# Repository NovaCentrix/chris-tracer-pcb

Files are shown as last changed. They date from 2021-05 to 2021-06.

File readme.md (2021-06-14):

# The TraceR 

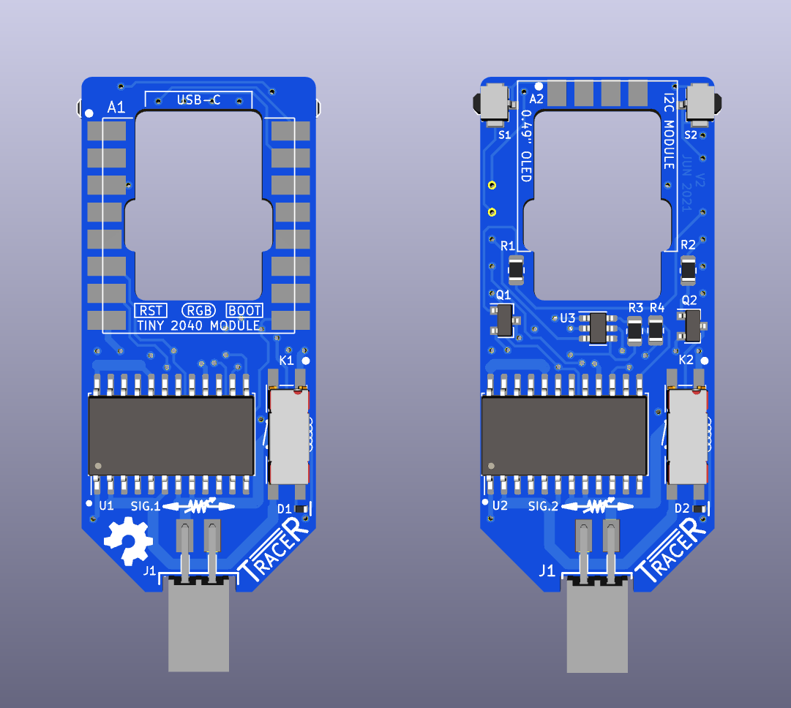
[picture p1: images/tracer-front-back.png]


## A Module for Simulating Conductive Ink PCB Traces

## Revisions

### Version 2

* Digipot power supply from from 3.3 to 5, in order to reduce the wiper
  resistance further (see the datasheet). This means the addition of
  level translator for the MISO signal into the MCU. 

* The digipot SDO pin is open drain. Added pullup resistors on each one.

* Assembly of modules onto v1 board was difficult. And the whole assembly 
  needs to be thinner so two modules can be installed adjacent to each
  other (relates to the pin header spacing on the main board). Gave up
  on the idea of avoiding a board cutout. Re-routing of signals, and
  made the board just slightly larger (mostly taller) to allow for the
  required cutout.

* Changed PCB thickness from 1.6 to 1.0 mm.

* Found some tiny buttons (about the same size as those on the Tiny 2040
  module) and put them at the top corners. This will allow the user to
  change resistance values without using the serial port.

### Version 1

First release. 

## Observations

Before I forget, here are some thoughts to consider if there ever is
going to be a version 3.

* Make D1/D2 larger, since that package is nearly impossible to hand
  solder. Or...

* Make the transistor and resistor packages smaller and reflow rather
  than hand solder. Also, Digipots are available in a smaller package:
    * TSSOP-24 package 7.8 x 4.4 mm 
    * SOIC-24W 15.4 x 7.5 mm (currently used)

* Look carefully at the Adafruit Qt Py RP2040 module. It looks smaller,
  has a smaller and well-defined required cutout and mechanical
  drawings. Fewer pins.

* Save even more space my tossing the module concept and building the
  RP2040 board and the OLED module directly on the TraceR's PCB.

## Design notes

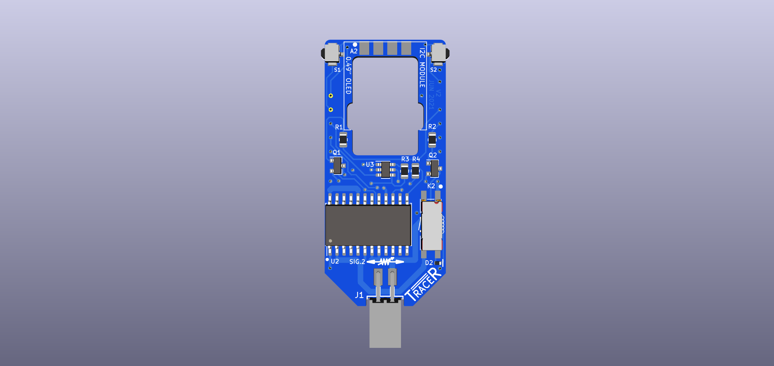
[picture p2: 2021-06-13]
images/tracer-back-view.png

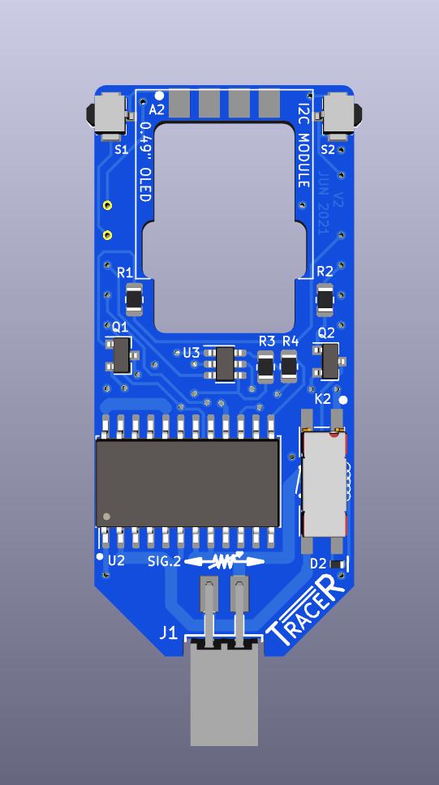
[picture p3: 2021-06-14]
images/b.png

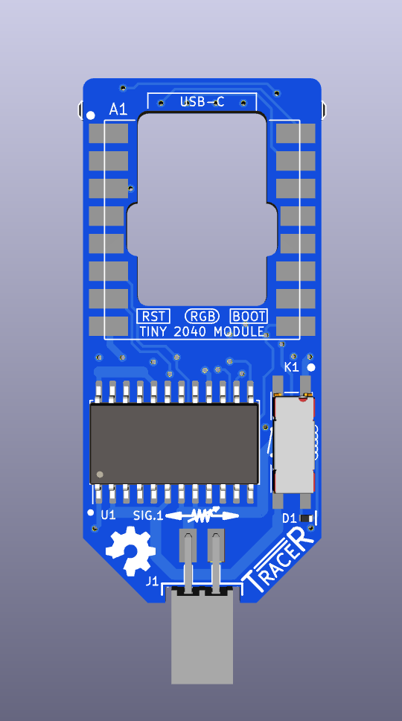
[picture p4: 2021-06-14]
images/f.png

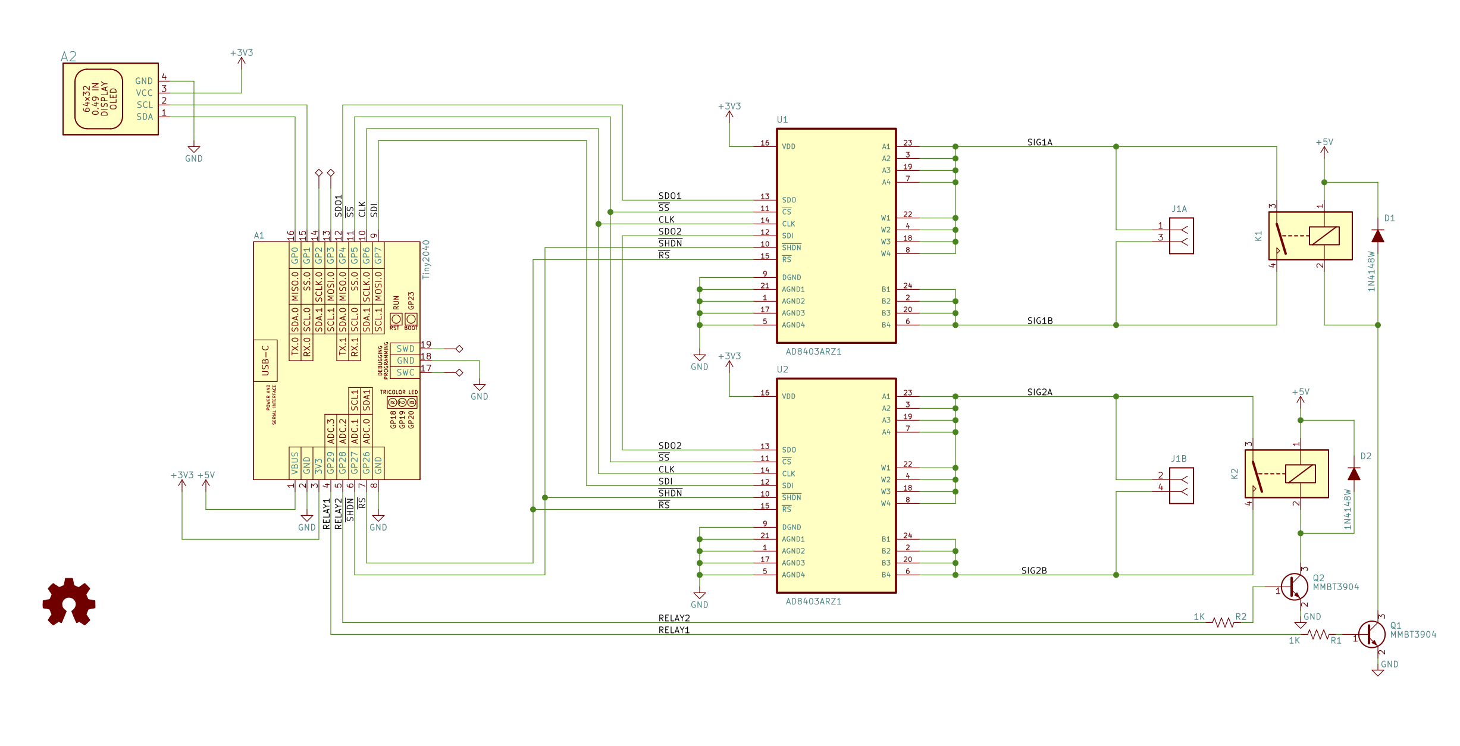
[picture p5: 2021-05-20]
tracer-sch.png

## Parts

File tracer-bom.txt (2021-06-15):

Reference	 Quantity	 Value	 Footprint	 Datasheet	 MANUFACTURER
A1 	1	"Tiny2040"	".tracer:MODULE_TINY_2040_DEV2"	""
A2 	1	"ASSY_OLED_490MILS_62x32_I2C"	".tracer:MODULE_OLED_490_SMALL_PADS"	""
U1 U2 	2	"AD8403ARZ1"	".tracer:SOIC-24W_7.5x15.4mm_P1.27mm"	""
U3 	1	"TXS0101"	".tracer:SOT-23-6"	""
Q1 Q2 	2	"MMBT3904"	".tracer:SOT-23"	"https://www.onsemi.com/pub/Collateral/2N3903-D.PDF"
D1 D2 	2	"1N4148W"	".tracer:DFN1006-2"	""
R1 R2 R3 R4 	4	"1K"	".tracer:R_0805_2012Metric"	""
K1 K2 	2	"Coto-9913-05-20"	".tracer:REED_RELAY_COTO_9913"	""
S1 S2 	2	"B3U-3100P-B"	".tracer:SW_B3U-3100P-B"	""	"Omron"
J1 	1	"IO_JACK_F04_SPLIT"	".tracer:SAMTEC-SSQ-102-02-SIDEWAYS"	""

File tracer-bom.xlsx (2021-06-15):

FN | QTY | REFDES | COMM | Mfr | PartNo | Item | Digikey P/N w/ Link
1 | 2 | U1 U2 | IC | Analog Devices | AD8403ARZ1 | IC, Analog, Digital Potentiometer | AD8403ARZ1-ND (https://www.digikey.com/en/products/detail/analog-devices-inc/AD8403ARZ1/997973)
2 | 1 | U3 | IC | Texas Instruments | TXS0101DBVR | IC, Level Translator, Single Gate | https://www.digikey.kr/product-detail/en/texas-instruments/TXS0101DBVR/2156-TXS0101DBVR-ND/13474289
3 | 2 | Q1 Q2 | SEMI | Diodes Inc | MMBT3904-7-F | Transistor, NPN, General Purpose 2N3904 SMD | MMBT3904-FDICT-ND (https://www.digikey.com/product-detail/en/diodes-incorporated/MMBT3904-7-F/MMBT3904-FDICT-ND/815727)
4 | 2 | D1 D2 | SEMI | MCC | 1N4148WL2 | Diode, General Purpose Signal 1N4148 SMD | 1N4148WL2-TPMSCT-ND (https://www.digikey.com/product-detail/en/micro-commercial-co/1N4148WL2-TP/1N4148WL2-TPMSCT-ND/6193205)
5 | 4 | R1 - R4 | RES | Yageo | RC0805JR-071KL |  | https://www.digikey.com/en/products/detail/yageo/RC0805JR-071KL/728218
6 | 2 | K1 K2 | REL | Coto Technology | 9913-05-20TR | Relay, Reed, 1 Form A, 5VDC Coil, SMD | 306-1415-1-ND (https://www.digikey.com/product-detail/en/coto-technology/9913-05-20TR/306-1415-1-ND/7398787)
7 | 2 | S1 S2 | SWI | Omron | B3U-3100P-B |  | https://www.digikey.com/en/products/detail/omron-electronics-inc-emc-div/B3U-3100P-B/1811780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
8 | 1 | J1 | CON | Samtec | SSQ-102-02-G-D | Connector, Pin Socket, 0.1 in pitch, 4 posn 2x2, Thruhole, Gold plating | SAM1185-02-ND (https://www.digikey.com/product-detail/en/samtec-inc/SSQ-102-02-G-D/SAM1185-02-ND/1110865)
2021-06-15 | Yellow items are new
2021-06-15 | Greeh highlight item is to buy

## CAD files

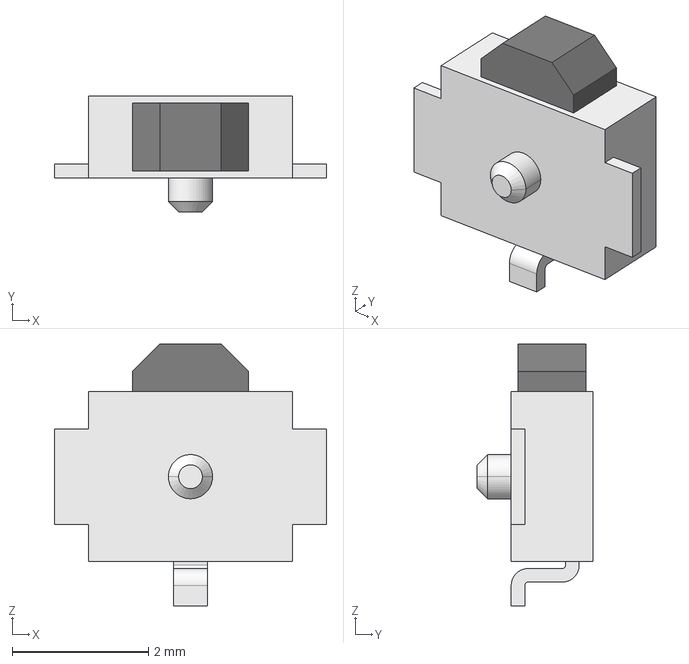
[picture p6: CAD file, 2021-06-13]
tracer.packages3d/b3u-3100p-b.stp
4.00 x 1.70 x 3.85 mm

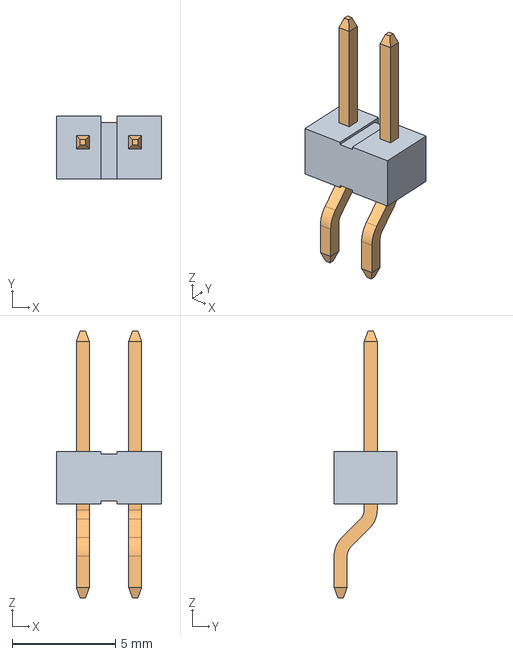
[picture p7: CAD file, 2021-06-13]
tracer.packages3d/TSM-102-01-L-SH.step
5.08 x 3.05 x 13.0 mm
_TSM-102-01-SH_body
_T-1S6-08(-01-2-SH)

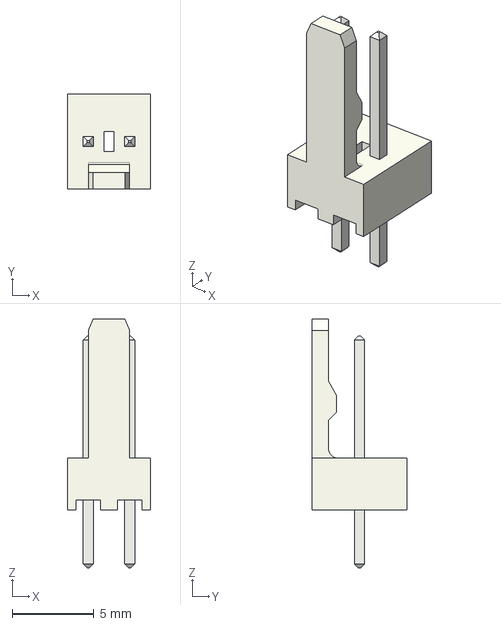
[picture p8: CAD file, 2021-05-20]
tracer.packages3d/Molex_KK-254_AE-6410-02A_1x02_P2.54mm_Vertical.step
5.08 x 5.80 x 15.3 mm

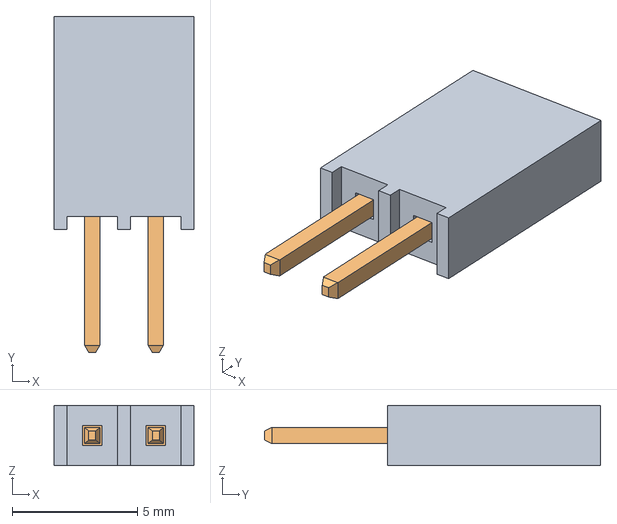
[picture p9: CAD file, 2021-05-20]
tracer.packages3d/SSQ-102-02-G-S.step
5.59 x 13.4 x 2.41 mm
_T1SSQ-102-02-G-S
_P2SSQ-102-02-G-S

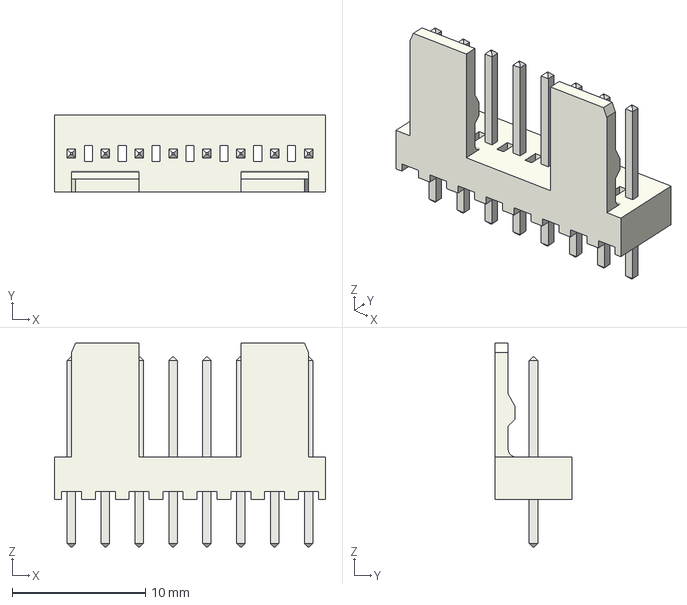
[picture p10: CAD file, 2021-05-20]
tracer.packages3d/Molex_KK-254_AE-6410-08A_1x08_P2.54mm_Vertical.step
20.3 x 5.80 x 15.3 mm

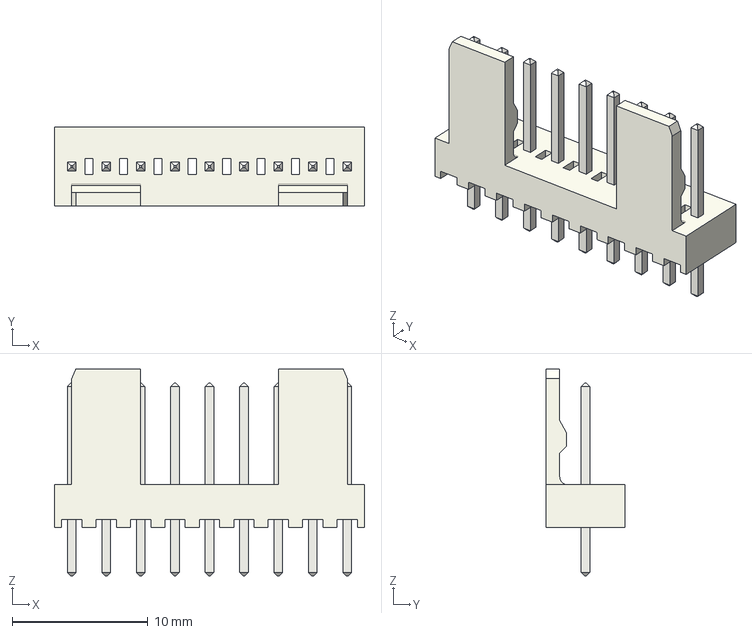
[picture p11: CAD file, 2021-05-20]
tracer.packages3d/Molex_KK-254_AE-6410-09A_1x09_P2.54mm_Vertical.step
22.9 x 5.80 x 15.3 mm

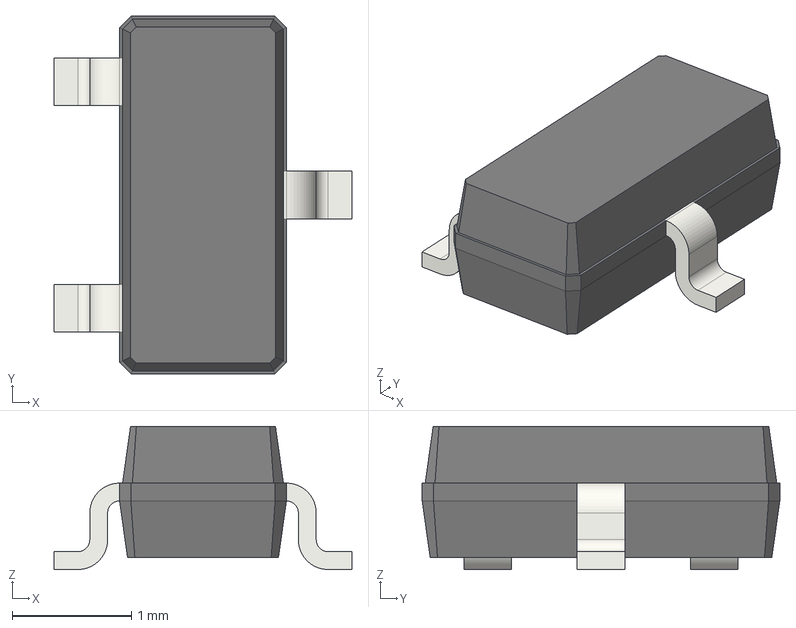
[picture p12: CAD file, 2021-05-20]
tracer.packages3d/SOT-23.step
2.50 x 3.00 x 1.20 mm

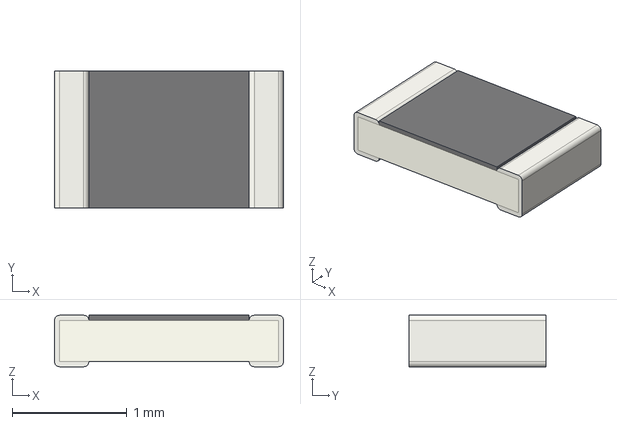
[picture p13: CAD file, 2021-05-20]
tracer.packages3d/R_0805_2012Metric.step
2.00 x 1.20 x 0.45 mm

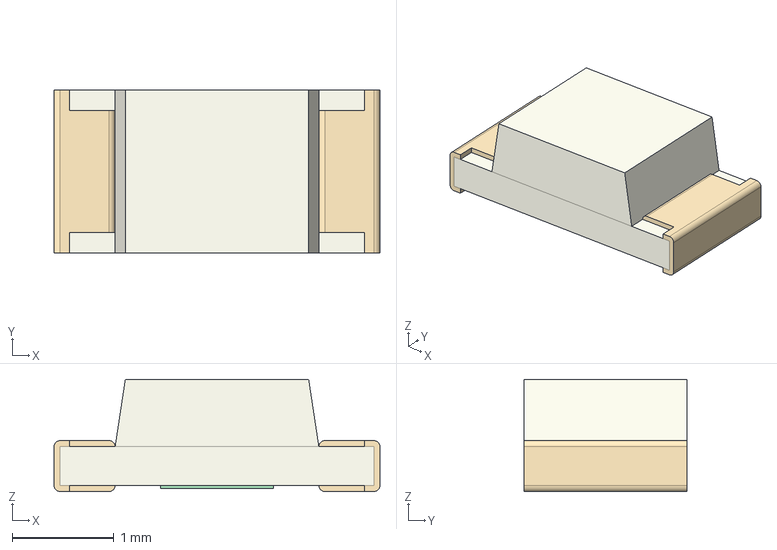
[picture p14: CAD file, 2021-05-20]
tracer.packages3d/LED_1206_3216Metric.step
3.20 x 1.60 x 1.10 mm

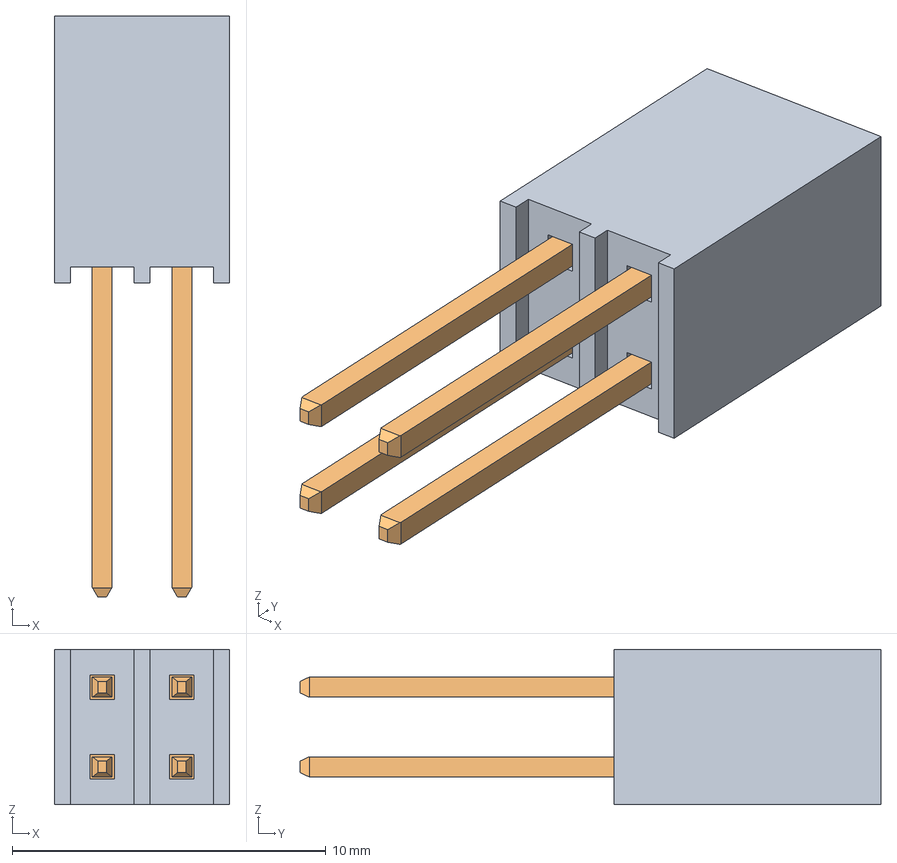
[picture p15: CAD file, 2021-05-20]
tracer.packages3d/SSQ-102-03-G-D.step
5.59 x 18.5 x 4.95 mm
_T1SSQ-102-03-G-D
_P2SSQ-102-03-G-D

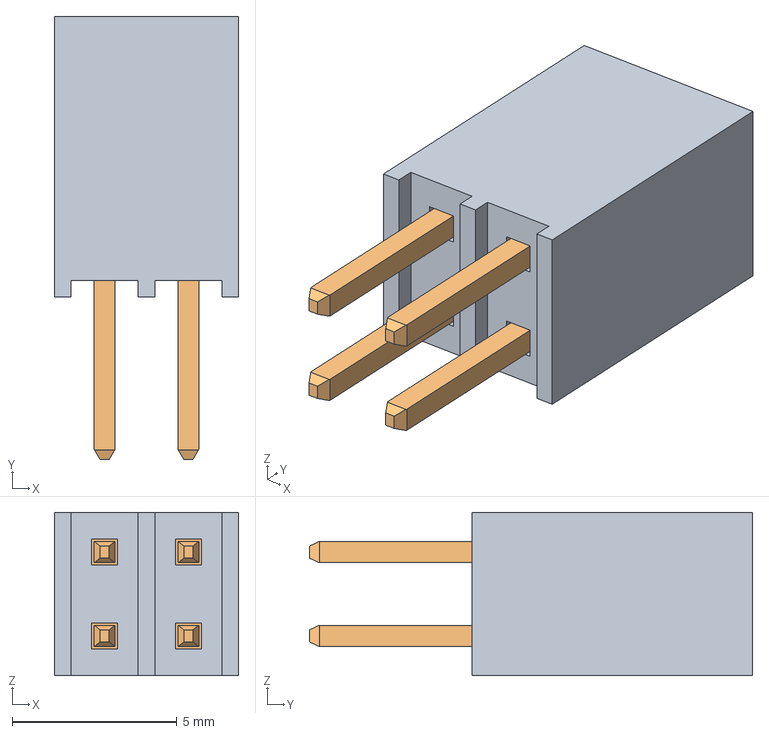
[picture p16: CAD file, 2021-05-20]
tracer.packages3d/SSQ-102-02-G-D.step
5.59 x 13.4 x 4.95 mm
_T1SSQ-102-02-G-D
_P2SSQ-102-02-G-D

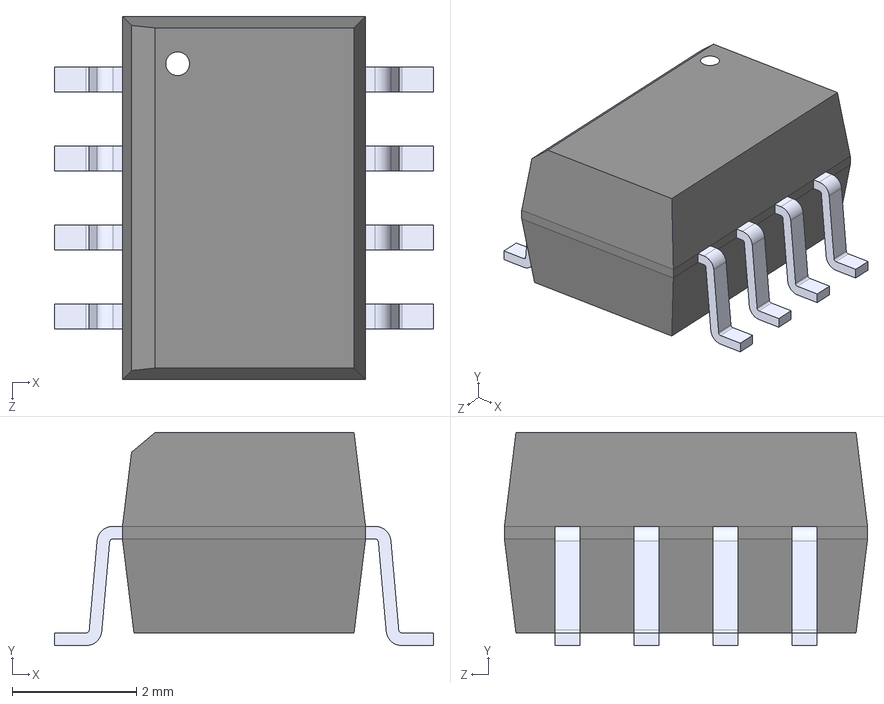
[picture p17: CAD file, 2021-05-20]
tracer.packages3d/ild213t.step
6.10 x 3.43 x 5.84 mm

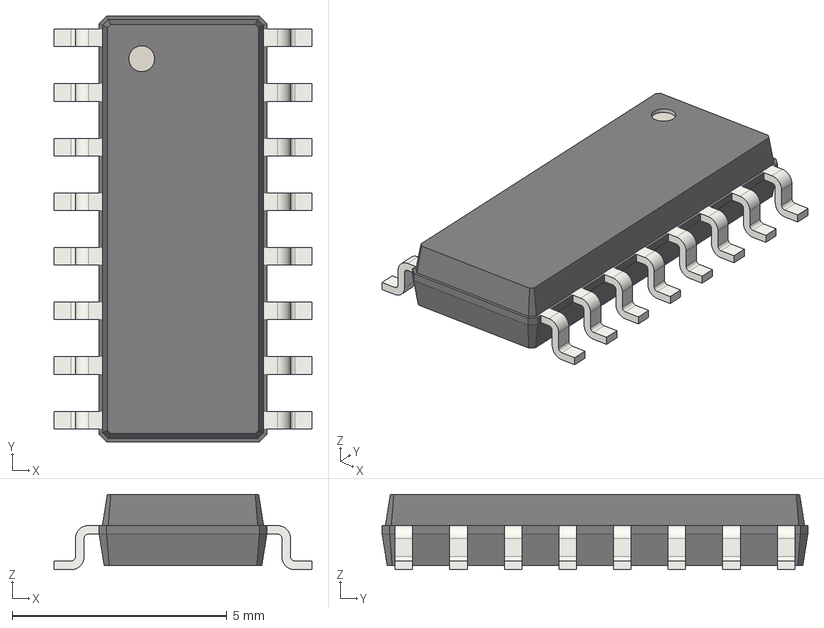
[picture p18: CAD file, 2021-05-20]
tracer.packages3d/SOIC-16_3.9x9.9mm_P1.27mm.step
6.00 x 9.90 x 1.75 mm

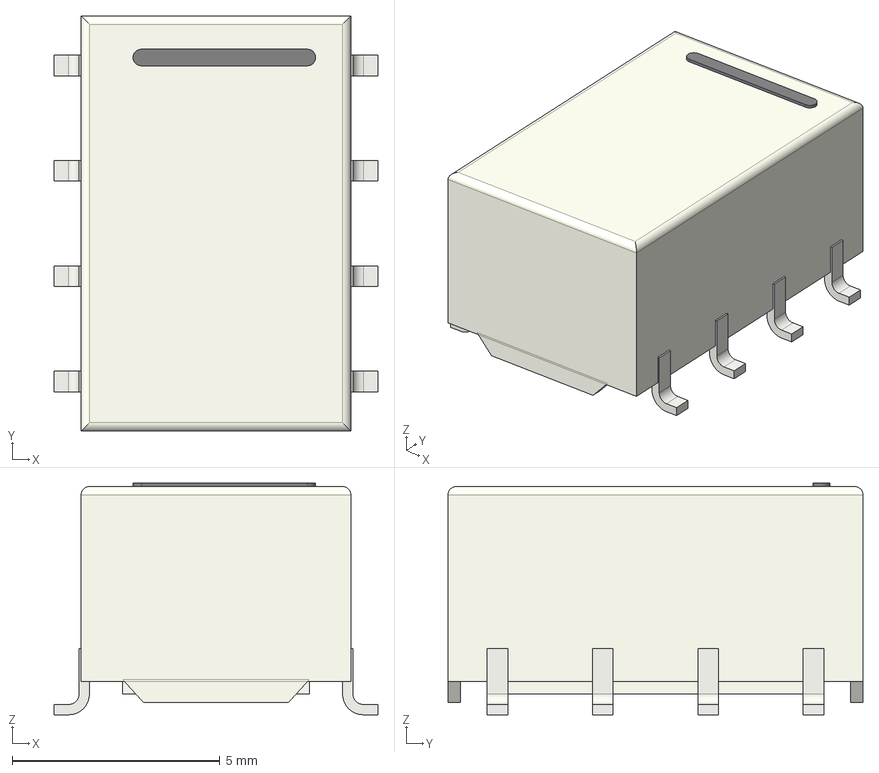
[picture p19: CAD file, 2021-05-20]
tracer.packages3d/Relay_DPDT_Omron_G6K-2F.step
7.80 x 10.0 x 5.58 mm

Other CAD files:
tracer.packages3d/plcc-2-package-3d.stp
tracer.packages3d/9913_stp.stp
tracer.packages3d/LED_1210_3225Metric.step
tracer.packages3d/Molex_KK-254_AE-6410-04A_1x04_P2.54mm_Vertical.step
tracer.packages3d/DFN1006-2.stp

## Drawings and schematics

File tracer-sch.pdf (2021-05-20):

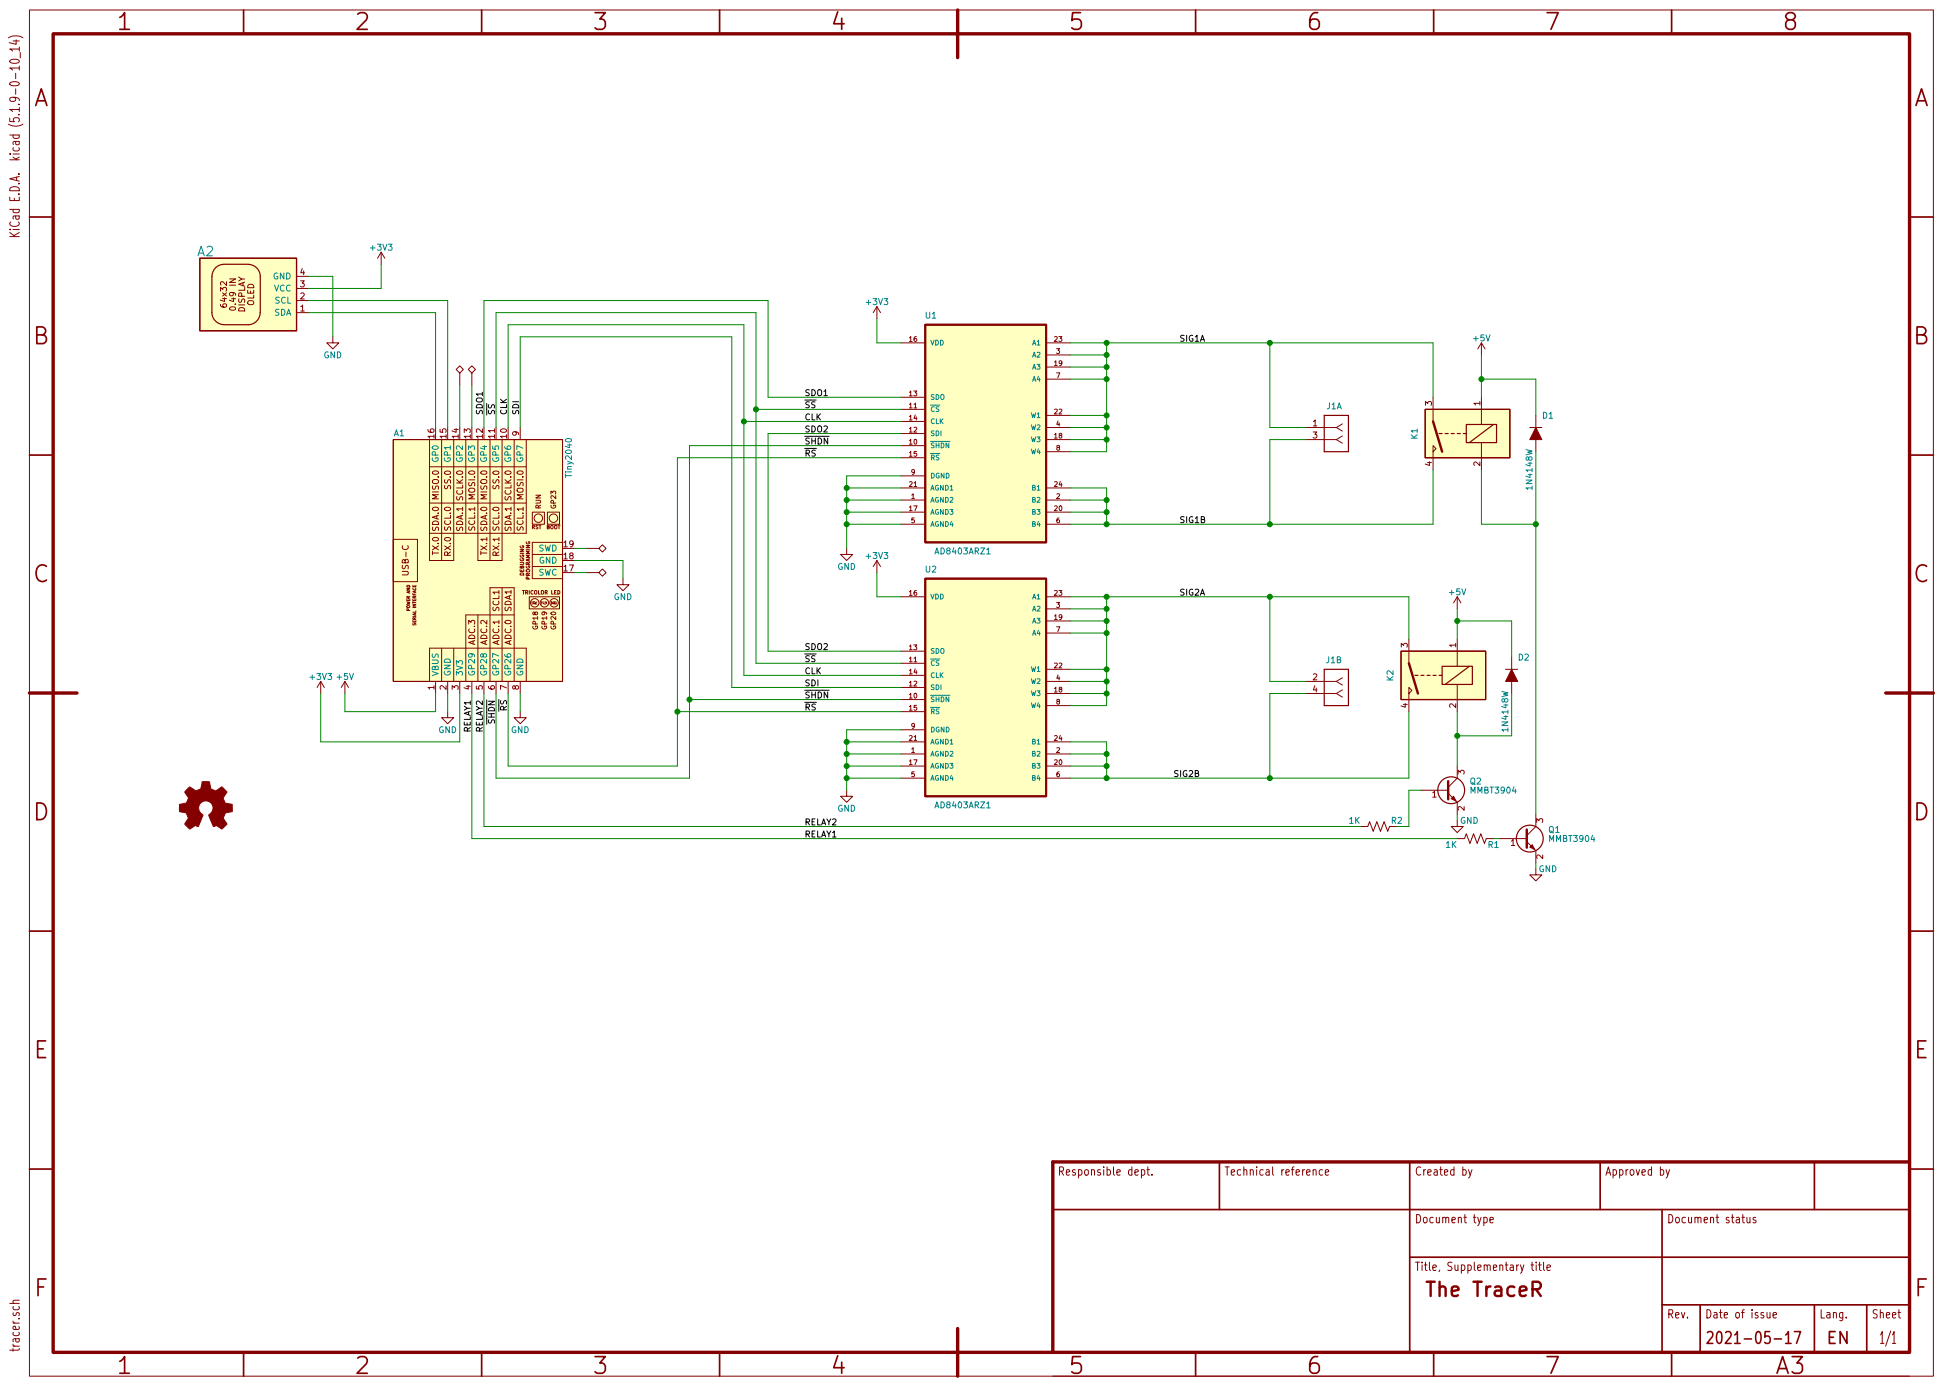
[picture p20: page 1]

The TraceR KiCad E.D.A. kicad (5.1.9-0-10_14)

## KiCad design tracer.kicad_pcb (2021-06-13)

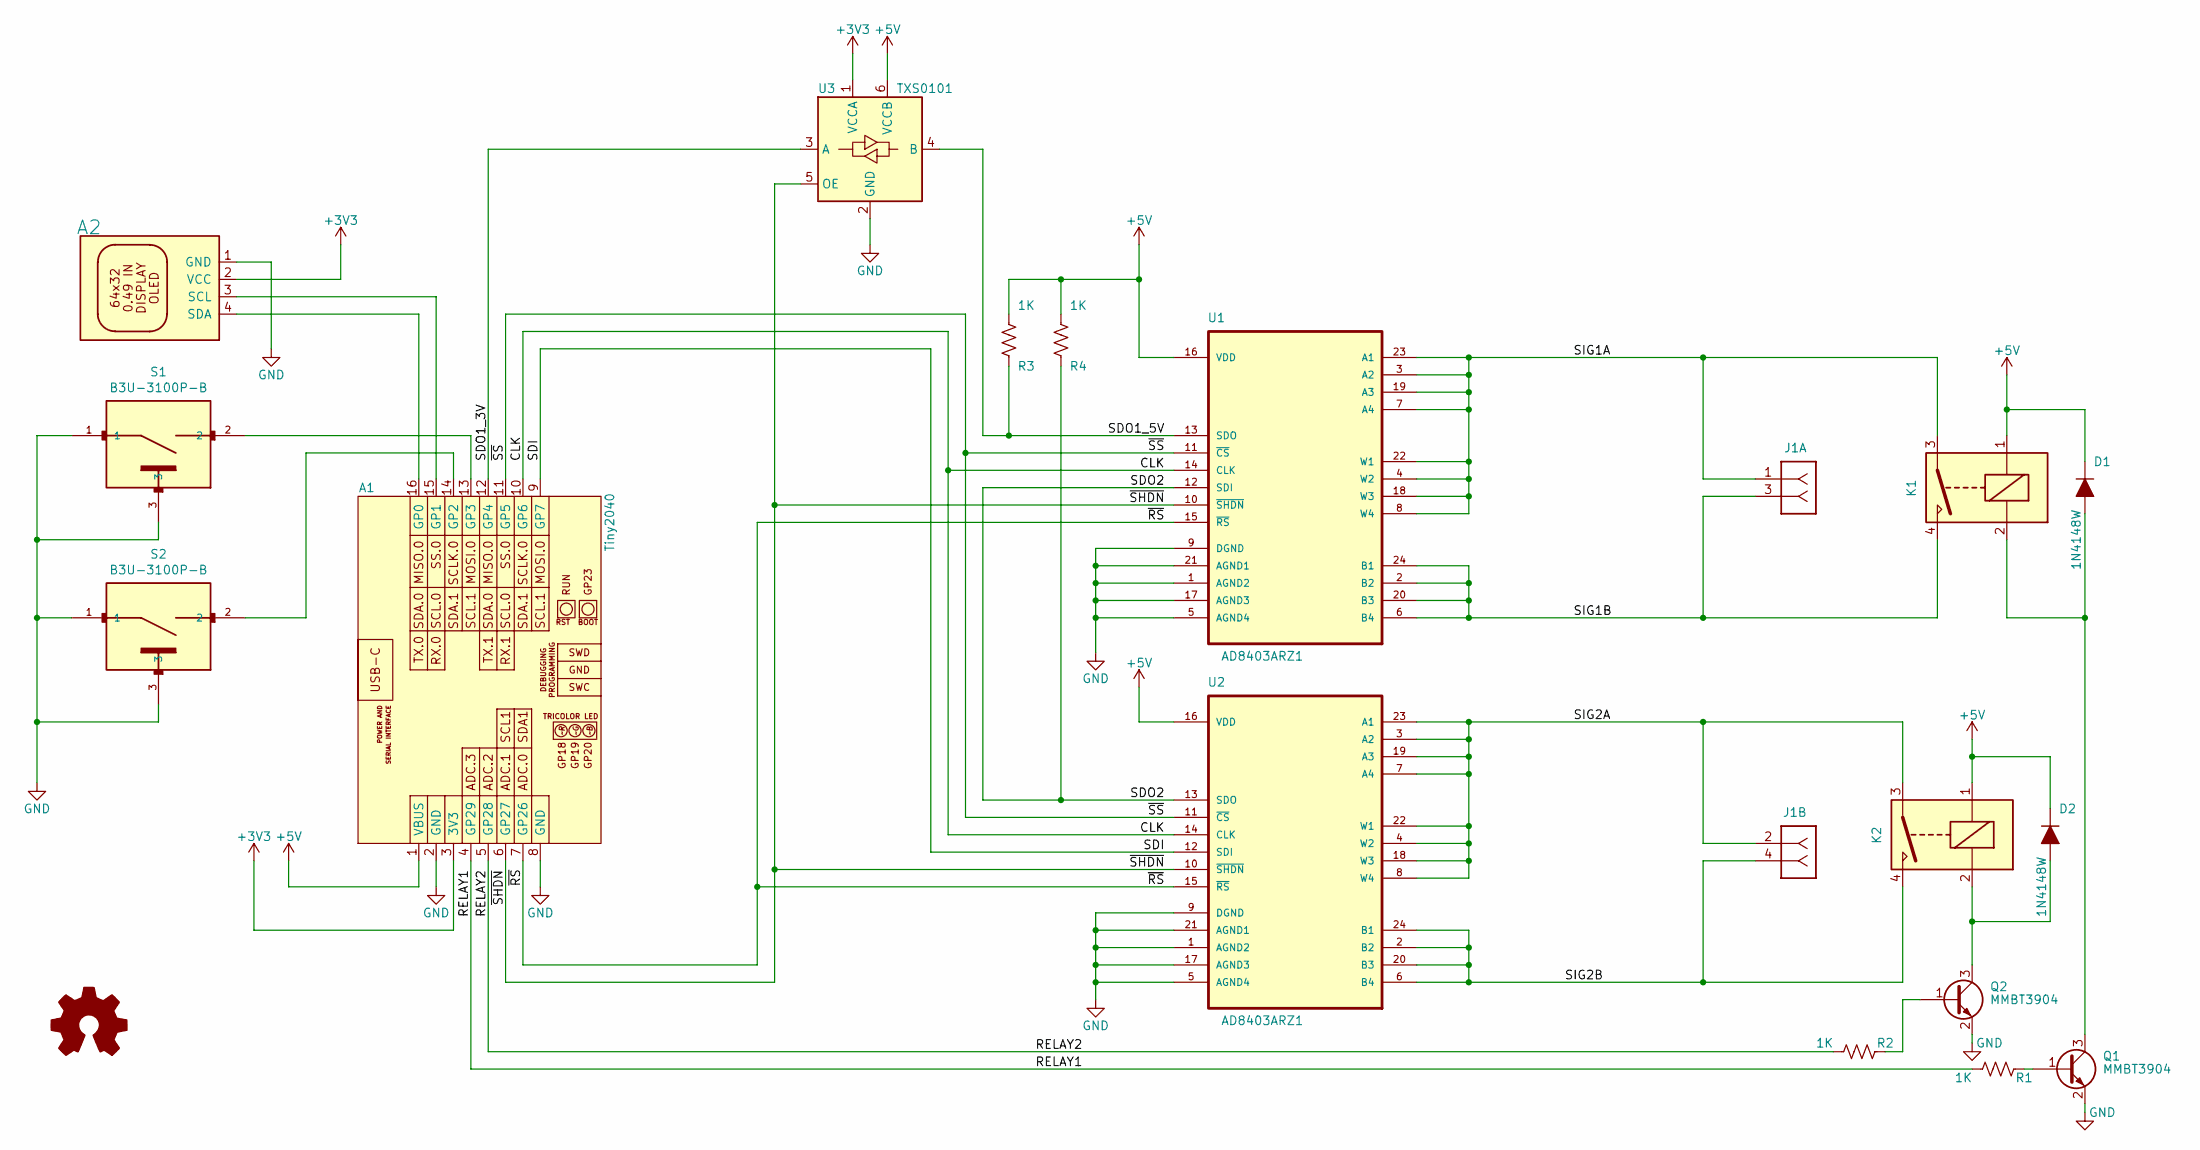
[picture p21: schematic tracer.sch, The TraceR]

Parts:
A1: Tiny2040; MODULE_TINY_2040_DEV2
A2: ASSY_OLED_490MILS_62x32_I2C; MODULE_OLED_490_SMALL_PADS
D1, D2: 1N4148W; DFN1006-2
J1: IO_JACK_F04_SPLIT; SAMTEC-SSQ-102-02-SIDEWAYS
K1, K2: Coto-9913-05-20; REED_RELAY_COTO_9913
LOGO1: Logo_Open_Hardware_Small; OSHW-Logo2_7.3x6mm_SilkScreen
Q1, Q2: MMBT3904; SOT-23
R1, R2, R3, R4: 1K; R_0805_2012Metric
S1, S2: B3U-3100P-B; SW_B3U-3100P-B
U1, U2: AD8403ARZ1; SOIC-24W_7.5x15.4mm_P1.27mm
U3: TXS0101; SOT-23-6

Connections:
+3V3: A1.3 (3V3), A2.2 (VCC), U3.1 (VCCA)
+5V: A1.1 (VBUS), D1.1 (K), D2.1 (K), K1.1, K2.1, R3.2, R4.2, U1.16 (VDD), U2.16 (VDD), U3.6 (VCCB)
/CLK: A1.10 (GP6), U1.14 (CLK), U2.14 (CLK)
/RELAY1: A1.4 (GP29), R1.2
/RELAY2: A1.5 (GP28), R2.2
/SDI: A1.9 (GP7), U2.12 (SDI)
/SDO1_3V: A1.12 (GP4), U3.3 (A)
/SDO1_5V: R3.1, U1.13 (SDO), U3.4 (B)
/SDO2: R4.1, U1.12 (SDI), U2.13 (SDO)
/SIG1A: J1.1, K1.3, U1.3 (A2), U1.4 (W2), U1.7 (A4), U1.8 (W4), U1.18 (W3), U1.19 (A3), U1.22 (W1), U1.23 (A1)
/SIG1B: J1.3, K1.4, U1.2 (B2), U1.6 (B4), U1.20 (B3), U1.24 (B1)
/SIG2A: J1.2, K2.3, U2.3 (A2), U2.4 (W2), U2.7 (A4), U2.8 (W4), U2.18 (W3), U2.19 (A3), U2.22 (W1), U2.23 (A1)
/SIG2B: J1.4, K2.4, U2.2 (B2), U2.6 (B4), U2.20 (B3), U2.24 (B1)
/~RS: A1.7 (GP26), U1.15 (~RS), U2.15 (~RS)
/~SHDN: A1.6 (GP27), U1.10 (~SHDN), U2.10 (~SHDN), U3.5 (OE)
/~SS: A1.11 (GP5), U1.11 (~CS), U2.11 (~CS)
GND: A1.2 (GND), A1.8 (GND), A2.1 (GND), Q1.2 (E), Q2.2 (E), S1.1, S1.3, S2.1, S2.3, U1.1 (AGND2), U1.5 (AGND4), U1.9 (DGND), U1.17 (AGND3), U1.21 (AGND1), U2.1 (AGND2), U2.5 (AGND4), U2.9 (DGND), U2.17 (AGND3), U2.21 (AGND1), U3.2 (GND)
unnamed 17: A1.13 (GP3), S1.2; also elsewhere on the board
unnamed 18: A1.14 (GP2), S2.2; also elsewhere on the board
unnamed: A1.15 (GP1), A2.3 (SCL)
unnamed: A1.16 (GP0), A2.4 (SDA)
unnamed: D1.2 (A), K1.2, Q1.3 (C)
unnamed: D2.2 (A), K2.2, Q2.3 (C)
unnamed: Q1.1 (B), R1.1
unnamed: Q2.1 (B), R2.1

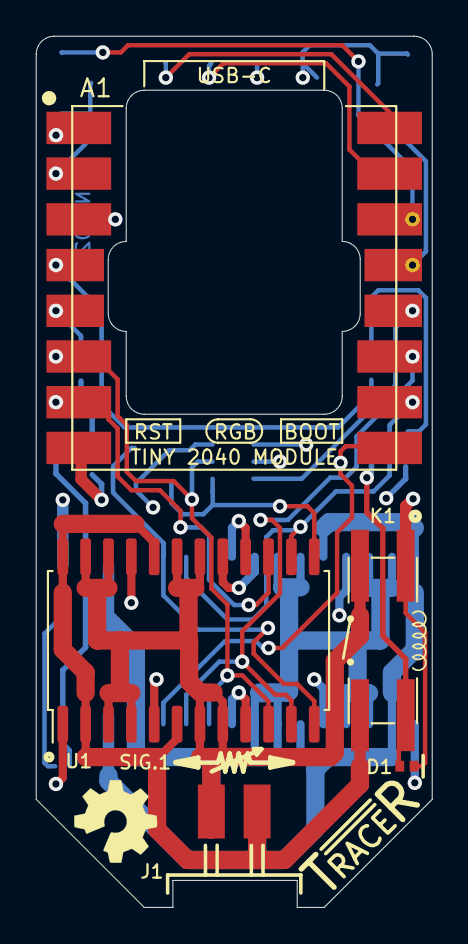
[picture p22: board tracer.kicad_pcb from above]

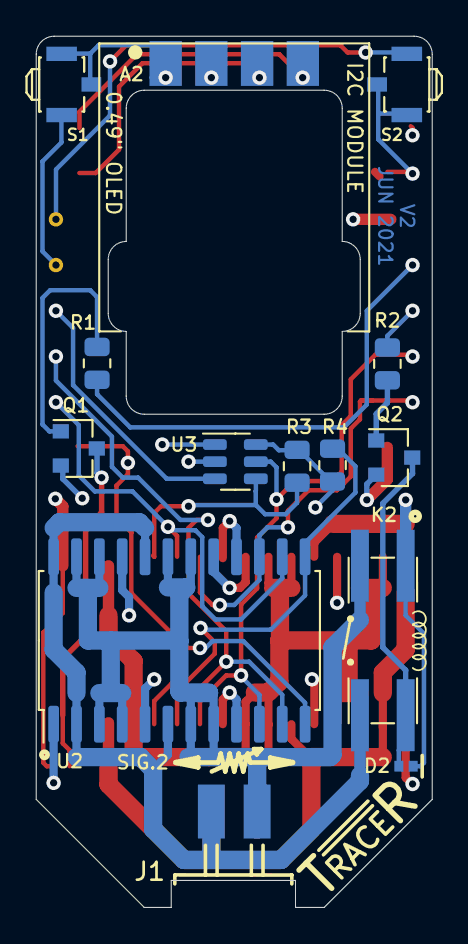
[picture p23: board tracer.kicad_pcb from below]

Board: 4 copper layers, 22.0 x 48.4 mm, 21 parts (13 on the bottom side), 25 nets.

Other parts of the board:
TP13, TP14: TestPoint; via-0.8x0.4

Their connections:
unnamed 17: TP13.1; also elsewhere on the board
unnamed 18: TP14.1; also elsewhere on the board

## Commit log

2021-05-20 initial release, version 1 PCB
    [tracer-B_Cu.gbr, tracer-B_Mask.gbr, tracer-B_SilkS.gbr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]
2021-05-20 Made Project Self-contained
    [9913_stp.stp, DFN1006-2.stp, LED_1206_3216Metric.step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]
2021-05-20 added schematic printouts
2021-05-24 changes for 5V/3.3V SDI
2021-06-13 v2 release to PCB shop
    [TSM-102-01-L-SH.step, b3u-3100p-b.stp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]
2021-06-15 updating BOM
    [tracer-bom.xlsx]

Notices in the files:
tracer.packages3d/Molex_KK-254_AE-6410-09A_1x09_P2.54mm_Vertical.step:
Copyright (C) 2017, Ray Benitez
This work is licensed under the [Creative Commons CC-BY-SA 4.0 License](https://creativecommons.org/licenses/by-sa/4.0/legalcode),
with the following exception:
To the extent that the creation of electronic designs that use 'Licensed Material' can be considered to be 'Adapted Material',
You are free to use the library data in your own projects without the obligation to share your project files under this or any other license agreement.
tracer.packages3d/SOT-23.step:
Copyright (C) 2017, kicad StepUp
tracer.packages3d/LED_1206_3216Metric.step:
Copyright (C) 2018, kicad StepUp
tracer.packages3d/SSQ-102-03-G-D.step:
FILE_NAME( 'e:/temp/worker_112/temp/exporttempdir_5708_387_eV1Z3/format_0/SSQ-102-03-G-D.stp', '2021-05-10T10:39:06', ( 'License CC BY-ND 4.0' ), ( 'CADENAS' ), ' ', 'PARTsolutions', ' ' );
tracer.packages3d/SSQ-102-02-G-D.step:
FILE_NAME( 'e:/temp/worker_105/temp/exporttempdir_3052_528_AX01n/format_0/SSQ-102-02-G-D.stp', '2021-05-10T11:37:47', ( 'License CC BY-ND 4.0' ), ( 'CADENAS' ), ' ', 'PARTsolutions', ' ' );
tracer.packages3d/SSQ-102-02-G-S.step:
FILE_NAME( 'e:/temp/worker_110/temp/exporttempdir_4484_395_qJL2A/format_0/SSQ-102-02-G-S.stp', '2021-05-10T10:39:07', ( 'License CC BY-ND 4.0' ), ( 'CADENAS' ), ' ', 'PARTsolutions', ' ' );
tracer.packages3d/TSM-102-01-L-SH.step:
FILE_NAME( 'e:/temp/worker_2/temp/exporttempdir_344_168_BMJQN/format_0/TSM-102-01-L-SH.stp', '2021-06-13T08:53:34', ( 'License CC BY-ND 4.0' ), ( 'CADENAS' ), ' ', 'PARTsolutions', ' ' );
